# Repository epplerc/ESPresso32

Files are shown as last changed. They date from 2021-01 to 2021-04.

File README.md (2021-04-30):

# ESPresso32

The goal of this project is to create a espresso scale based on a ESP32 with
a corresponding Android App and Bluetooth Low Energy connection.

The ESP32 is programmed with the Arduino IDE.

A [demonstration video](https://youtu.be/5yW7n7iKzck) can be found on youtube.

## ESP32

### Software
You need the Arduino IDE to flash the software.
Simple flash the espresso32.ino file this is all.

Now you can install the Android app or use direct Bluetooth Low Energy
to communicate with the scale.

### Calibration
Your build scale will properly not sow correct values from the start.
To get correct values the scale need to be calibrated to do this
you need  a something where you know the weight.
At best it should not be to light.
Now start the scale but the calibration weight on it and start the [calibration modus](#characteristics).
If you want you can set a start calibration value for the auto calibration or determine a calibration
value by your own.
The calibration is done when the scale show the weight of you calibration weight.
You can monitor the status of the calibration with the [status characteristic](#characteristics).

This calibration value need to be set on every start of the scale. The android app to this on his own.

### Hardware setup
Beside of the software i have use a simple hardware setup which should only be a example without warranty.

#### List of components
Below you see a list of component i have used.
The advantage of the LiFePo4 accumulator are that they deliver a voltage from
max 3.6V which is the max voltage the ESP32 can be run direct on the 3.3V input.
So i was able to omitting one voltage converter.
As ESP32 i have used a plain wroom on a small circuit board.
If you want to do this too you need also a UART adapter to flash the ESP32.
You can also use a NodeMCU but this need more space and power.

- ESP32
- Load cell
- HX711
- Battery holder
- LiFePo4 accumulator
- Step up (MT3608)
- Housing ( **[My stl files are located here ](stl)**)
- (Optional) UART adapter
- Other small parts like wires etc

This is only a  simple example there for sure other setups possible.

**_NOTE:_** Depending on which HX711 module you have to should have a look here: [module design fault fix](https://github.com/bogde/HX711/issues/172)

#### Schematic

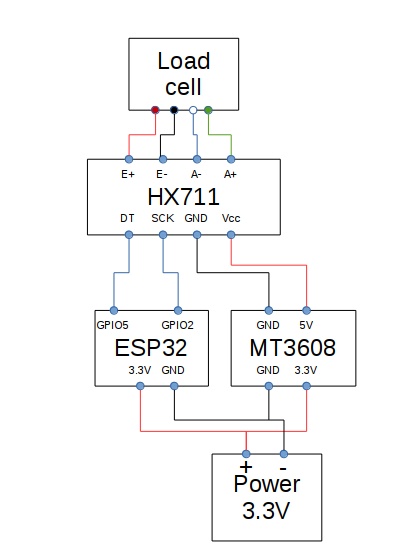
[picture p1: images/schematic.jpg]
Schematic


## Android
To use the android application you need a phone with **Bluetooth Low Energy**.

You can install the app from the [Playstore](https://play.google.com/store/apps/details?id=org.weblooker.espresso32) or build the app from the source.

If you want to build your application from the source you can do this.
The code is located in the folder  **[android](android)**.

## Bluetooth

### Service
The service UUID from the scale is **dff971a9-142a-4021-a8d2-f5298ab2bdbb**.

### Characteristics
Name | UUID | Read/Write  | Description | Value
------ | ------| ------| ------| ------
Settings   | 76053035-3aa1-4148-a70d-a73e35332418| x/x| Set the modus of the scale| tare, WEIGHT_MODUS, ESPRESSO_MODUS, CALIBRATION_MODUS
Status   | c5c78e8f-5963-4642-bd24-bbb8507e22ca|  x/-| Show the status of the scale|
Calibration weight   | 18d456b3-3c7b-43fa-9d3c-db867d2a93b2|  x/x| Calibration weight | Weight in g|
Calibration value   | e5c96eed-c523-4e81-9d8b-1f92f58603dc| x/x| Set a calibration value of get the determined one | 
Weight   | 2A98| x/-| Weight| Weight in g
Espresso weight   | d0dac8e6-cf56-4e0c-9823-0aed58dc9bfe|  x/-| The weight in g of espresso| 
Espresso time  | 6e980e27-b771-485a-8396-42f1dab56506|  x/-| Time| 

## Known Issues

### Espresso time is stop to early
Depending from your setup this can happen if you use a light espresso cup like a 
thermoglass in combination with vibrations from the pump. 
A simple fix is to use a heavy espresso cup. If this is not possible you need to play 
around with the threshold on the **messure_espresso()** function.
In future maybe this will configurable from the app.

## License

Copyright 2021 Christian Eppler

Licensed under the Apache License, Version 2.0 (the "License");
you may not use this file except in compliance with the License.
You may obtain a copy of the License at

    http://www.apache.org/licenses/LICENSE-2.0

Unless required by applicable law or agreed to in writing, software
distributed under the License is distributed on an "AS IS" BASIS,
WITHOUT WARRANTIES OR CONDITIONS OF ANY KIND, either express or implied.
See the License for the specific language governing permissions and
limitations under the License.

[Long License text](LICENSE)

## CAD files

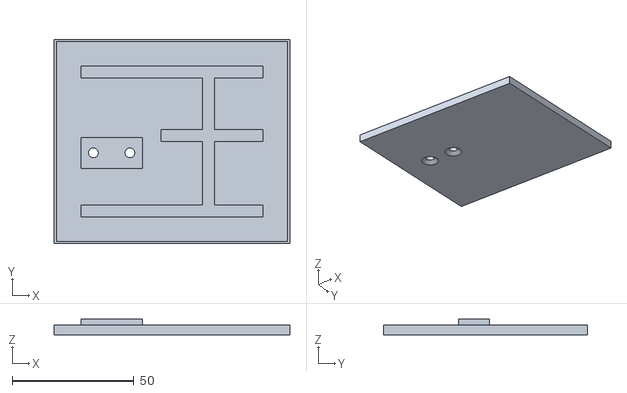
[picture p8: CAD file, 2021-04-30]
stl/top.stl
97.0 x 84.0 x 6.50

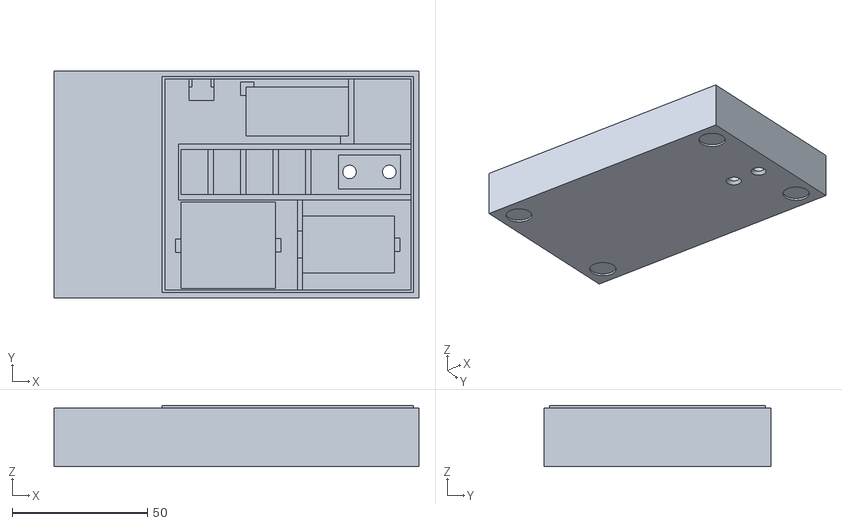
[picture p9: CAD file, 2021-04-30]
stl/housing.stl
135.0 x 84.0 x 22.7

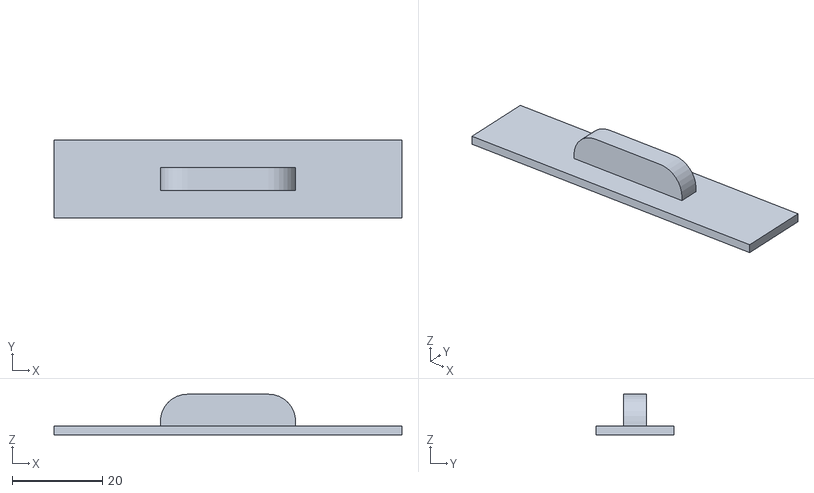
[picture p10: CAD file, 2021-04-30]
stl/lid.stl
77.2 x 17.2 x 9.00

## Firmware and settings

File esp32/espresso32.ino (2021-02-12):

#include "HX711.h"
#include <BLEDevice.h>
#include <BLEUtils.h>
#include <BLEServer.h>
#include <EEPROM.h>
#include <WiFi.h>

#define DEBUG false

#define LOADCELL_DOUT_PIN  5
#define LOADCELL_SCK_PIN  2
#define EEPROM_SIZE 5
#define EEPROM_VALUE_IS_STORED 142

#define WEIGHT_SERVICE_UUID "dff971a9-142a-4021-a8d2-f5298ab2bdbb"
#define SETTINGS_CHARACTERISTIC_UUID "76053035-3aa1-4148-a70d-a73e35332418"
#define STATUS_CHARACTERISTIC_UUID "c5c78e8f-5963-4642-bd24-bbb8507e22ca"
#define CALIBRATION_WEIGHT_CHARACTERISTIC_UUID "18d456b3-3c7b-43fa-9d3c-db867d2a93b2"
#define CALIBRATION_VALUE_CHARACTERISTIC_UUID "e5c96eed-c523-4e81-9d8b-1f92f58603dc"
#define WEIGHT_CHARACTERISTIC_UUID "2A98"
#define ESPRESSO_WEIGHT_CHARACTERISTIC_UUID "d0dac8e6-cf56-4e0c-9823-0aed58dc9bfe"
#define ESPRESSO_TIME_CHARACTERISTIC_UUID "6e980e27-b771-485a-8396-42f1dab56506"

HX711 scale;

union {
  float floatingpoint;
  char bytes[4];
} calibration_factor_union;
float default_calibration_factor = 4386.18; 

float tare_value = 0.0;
float weight = 0.0;
float tared_weight = 0.0;
float calibration_weight = 0.0;
boolean calibration_weight_is_set = false;

String modus = "WEIGHT_MODUS";
String state = "READY";

unsigned long espresso_start;
unsigned long espresso_end;
unsigned long espresso_time;

BLEServer *pServer;
BLEService *pService;
BLECharacteristic *pCharacteristicWeight;
BLECharacteristic *pCharacteristicCalibrationWeight;
BLECharacteristic *pCharacteristicCalibrationValue;
BLECharacteristic *pCharacteristicSettings;
BLECharacteristic *pCharacteristicStatus;
BLECharacteristic *pCharacteristicEspressoWeight;
BLECharacteristic *pCharacteristicEspressoTime;

float loadCalibrationValueFromFlash()
{
   if(EEPROM_VALUE_IS_STORED == EEPROM.read(4))
   {
      for(int i=0;i<4;i++)
      {
        calibration_factor_union.bytes[i] = EEPROM.read(i);
      }
      return calibration_factor_union.floatingpoint;
   }
   
   calibration_factor_union.floatingpoint = default_calibration_factor;
   return calibration_factor_union.floatingpoint;
}

void storeCalibrationValuetoFlash(float calvalue)
{
   calibration_factor_union.floatingpoint = calvalue;
  
   for(int i=0;i<4;i++)
    EEPROM.write(i,calibration_factor_union.bytes[i]);

   EEPROM.write(4,EEPROM_VALUE_IS_STORED);
   EEPROM.commit();
}

void setStatus(String state_param)
{
    state = state_param;
    pCharacteristicStatus->setValue(state.c_str());
    pCharacteristicStatus->notify();
}

void setModus(String modusParam)
{
  modus= modusParam;
  pCharacteristicSettings->setValue(modus.c_str());
  pCharacteristicSettings->notify();
}

void setCalibrationFaktor(float faktore)
{
   char result[50];
   sprintf(result,"%f",faktore);
   pCharacteristicCalibrationValue->setValue(result);
   pCharacteristicCalibrationValue->notify();
}

void setEspressoResult(long espresso_time,float tared_weight)
{
   String result = String();
   result.concat("{\"results\":[");
   char tmp_result[50];
   sprintf(tmp_result,"{\"t\":%d,\"w\":%.2f}",espresso_time,tared_weight);
   result.concat(String(tmp_result));
   result.concat("]}");
  
  char timeString[50];
  result.toCharArray(timeString,50); 
  pCharacteristicEspressoTime->setValue(timeString); 
  pCharacteristicEspressoTime->notify();
}

void setEspressoResults(unsigned long _times[], float weights[])
{
   char char_result[300];
   memset(char_result,'\0', 300);
   String result = String();
   result.concat("{\"results\":[");
   int delay_counter = 0;
   for(int i=0;i<10;i++)
   {
     if(weights[i] >= 0.0)
     {
       delay_counter++;
       char tmp_result[35];
       memset(tmp_result,'\0', sizeof(tmp_result));
       sprintf(tmp_result,"{\"t\":%d,\"w\":%.2f}",_times[i],weights[i]);
       result.concat(tmp_result);
  
       if(i >= 9)
        continue;

       if(weights[i+1] >= 0.0)
       {
         result.concat(',');
       }
       
     }
   }
   result.concat("]}");
   result.toCharArray(char_result,300); 

  pCharacteristicEspressoTime->setValue(char_result); 
  pCharacteristicEspressoTime->notify();
  delay(50*delay_counter); // Waiting until data is send
}

void setWeight(float weight_param)
{
  weight = weight_param;
  char floatString[20];
  sprintf(floatString,"%.2f",tared_weight);
  tared_weight = tareWeight(weight_param);
  pCharacteristicWeight->setValue(floatString);
  pCharacteristicWeight->notify();
#if DEBUG
  char output[50];
  sprintf(output,"Weight %.2f g",tared_weight);
  Serial.println(output);
#endif
}

class MyCallbacks: public BLECharacteristicCallbacks {
  
    void onWrite(BLECharacteristic *pCharacteristic) 
    {
      std::string value = pCharacteristic->getValue();
      if (value.length() > 0) 
      {
        String val = "";
        for (int i = 0; i < value.length(); i++){
          val  = val + value[i];
        }
#if DEBUG        
        Serial.println("Get value:"+val);
#endif        
        if(value == "tare")
        {
#if DEBUG           
           Serial.println("Tare weight");
#endif
           tare_value = weight;
        }
        if(value == "WEIGHT_MODUS")
        {
#if DEBUG
           Serial.println("Set modus to WEIGHT_MODUS");
#endif
           setModus("WEIGHT_MODUS");
        }
        if(value == "ESPRESSO_MODUS")
        {
#if DEBUG 
           Serial.println("Set modus to ESPRESSO_MODUS");
#endif
           setModus("ESPRESSO_MODUS");
        }
        if(value == "CALIBRATION_MODUS")
        {
#if DEBUG 
           Serial.println("Set modus to CALIBRATION_MODUS");
#endif
           setModus("CALIBRATION_MODUS");
        }
        
      }
    }
};

class CalibrationWeightCallbacks: public BLECharacteristicCallbacks {
  
    void onWrite(BLECharacteristic *pCharacteristic) 
    {
      std::string value = pCharacteristic->getValue();
      if (value.length() > 0) 
      {
        String val = "";
        for (int i = 0; i < value.length(); i++){
          val  = val + value[i];
        }
#if DEBUG 
        Serial.println("Get value:"+val);
#endif
        calibration_weight = val.toFloat();
        calibration_weight_is_set = true; 
      }
    }
};

class CalibrationValueCallbacks: public BLECharacteristicCallbacks {
  
    void onWrite(BLECharacteristic *pCharacteristic) 
    {      
      std::string value = pCharacteristic->getValue();
      if (value.length() > 0) 
      {
        String val = "";
        for (int i = 0; i < value.length(); i++){
          val  = val + value[i];
        }
#if DEBUG 
        Serial.println("Get value:"+val);
#endif

        storeCalibrationValuetoFlash(val.toFloat());
        scale.set_scale(calibration_factor_union.floatingpoint);
      }
    }
};

void setup() {
  Serial.begin(9600);

  WiFi.mode( WIFI_MODE_NULL );

  EEPROM.begin(EEPROM_SIZE);
  loadCalibrationValueFromFlash();

  int i = 0;
  while(!scale.is_ready())
  {
    scale.begin(LOADCELL_DOUT_PIN, LOADCELL_SCK_PIN);

    if(i > 0)
    {
      delay(100);
      Serial.println("Can't detect scale.");
    }
    i++;
  }
  scale.set_scale();
  scale.set_gain((byte)128);
  scale.tare();
  scale.set_scale(calibration_factor_union.floatingpoint);

  BLEDevice::init("ESPresso32");
  pServer = BLEDevice::createServer();
  pService = pServer->createService(WEIGHT_SERVICE_UUID);

  // BLECharacteristic::PROPERTY_WRITE
  pCharacteristicWeight = pService->createCharacteristic(
                                         WEIGHT_CHARACTERISTIC_UUID,
                                         BLECharacteristic::PROPERTY_READ|
                                         BLECharacteristic::PROPERTY_NOTIFY |
                                         BLECharacteristic::PROPERTY_INDICATE
                                       );

                                       
  pCharacteristicSettings = pService->createCharacteristic(
                                         SETTINGS_CHARACTERISTIC_UUID,
                                         BLECharacteristic::PROPERTY_READ |
                                         BLECharacteristic::PROPERTY_WRITE|
                                         BLECharacteristic::PROPERTY_NOTIFY |
                                         BLECharacteristic::PROPERTY_INDICATE
                                       );
  pCharacteristicEspressoWeight = pService->createCharacteristic(
                                         ESPRESSO_WEIGHT_CHARACTERISTIC_UUID,
                                         BLECharacteristic::PROPERTY_READ|
                                         BLECharacteristic::PROPERTY_NOTIFY |
                                         BLECharacteristic::PROPERTY_INDICATE
                                       );
  pCharacteristicEspressoTime = pService->createCharacteristic(
                                         ESPRESSO_TIME_CHARACTERISTIC_UUID,
                                         BLECharacteristic::PROPERTY_READ|
                                         BLECharacteristic::PROPERTY_NOTIFY |
                                         BLECharacteristic::PROPERTY_INDICATE
                                       );
  pCharacteristicStatus = pService->createCharacteristic(
                                         STATUS_CHARACTERISTIC_UUID,
                                         BLECharacteristic::PROPERTY_READ|
                                         BLECharacteristic::PROPERTY_NOTIFY |
                                         BLECharacteristic::PROPERTY_INDICATE
                                       );
  pCharacteristicCalibrationWeight = pService->createCharacteristic(
                                         CALIBRATION_WEIGHT_CHARACTERISTIC_UUID,
                                         BLECharacteristic::PROPERTY_READ |
                                         BLECharacteristic::PROPERTY_WRITE |
                                         BLECharacteristic::PROPERTY_NOTIFY |
                                         BLECharacteristic::PROPERTY_INDICATE
                                        );
  pCharacteristicCalibrationValue = pService->createCharacteristic(
                                         CALIBRATION_VALUE_CHARACTERISTIC_UUID,
                                         BLECharacteristic::PROPERTY_READ |
                                         BLECharacteristic::PROPERTY_WRITE|
                                         BLECharacteristic::PROPERTY_NOTIFY |
                                         BLECharacteristic::PROPERTY_INDICATE
                                         );

  pCharacteristicSettings->setCallbacks(new MyCallbacks());
  pCharacteristicCalibrationWeight->setCallbacks(new CalibrationWeightCallbacks());
  pCharacteristicCalibrationValue->setCallbacks(new CalibrationValueCallbacks());
 
  
  pService->start();
  BLEAdvertising *pAdvertising = BLEDevice::getAdvertising();
  pAdvertising->addServiceUUID(WEIGHT_SERVICE_UUID);
  pAdvertising->setScanResponse(true);
  pAdvertising->setMinPreferred(0x06);
  pAdvertising->setMinPreferred(0x12);
  BLEDevice::startAdvertising();

  setModus("WEIGHT_MODUS");
  setCalibrationFaktor(calibration_factor_union.floatingpoint);
  setStatus("READY");
}

void tare()
{
  tare_value += tared_weight;
}

void messure_weight()
{
#if DEBUG
  Serial.print("Reading: ");
#endif
  setWeight(scale.get_units(5));
}

void messure_weight_calibrate()
{
#if DEBUG
  Serial.print("Reading: ");
#endif
  setWeight(scale.get_units(10));
}

void messure_weight_fast()
{
#if DEBUG 
  Serial.print("Reading fast: ");
#endif
  setWeight(scale.get_units(1));
}

float tareWeight(float weight_param)
{
  return weight_param - tare_value;
}

//TODO  make a reset that we not get into infinite loop
// have in minde negative values (do a error flag and make a reboot posible from bluethooth?)
void messure_espresso()
{

  setStatus("TARE");
  do{
#if DEBUG
    Serial.println("Tare...");
#endif
    tare();
    delay(100);
    messure_weight();
  }while(tared_weight > 0.1);
#if DEBUG     
  Serial.print("Waiting for coffee..");
#endif
  setStatus("WAITING");
  
  float start_weight = scale.get_units(3);
  int sameCounter = 0;
  int tmp_index = 0;
  float tmp_weights[10] = {-1,-1,-1,-1,-1,-1,-1,-1,-1,-1};
  unsigned long tmp_times[10] = {-1,-1,-1,-1,-1,-1,-1,-1,-1,-1};
  while(true)
  {
    float tmp_weight = scale.get_units(3);
    if(tmp_weight-start_weight > 0.2)
    {      
      
      if(sameCounter == 0)
      {
       espresso_start = millis();
      }

      setWeight(tmp_weight);
      tmp_weights[tmp_index] = tared_weight;
      tmp_times[tmp_index] = millis()-espresso_start;
      tmp_index++;
      sameCounter++;
    }
    else
    {
      for(int i=0;i<10;i++)
      {
        tmp_weights[i] = -1;
        tmp_times[i] = -1;
      }
      tmp_index = 0; 
      sameCounter=0;
    }

    
    if(start_weight-tmp_weight > 0.2 )
    {
#if DEBUG
      Serial.print("Seem to me that the weight of the cup has changed will tare this. ;-)");
#endif
      setWeight(scale.get_units(3));
      tare();
      start_weight = scale.get_units(3);
    }

    if(sameCounter >= 7)
    {
      break;  
    }
#if DEBUG   
    Serial.println("Waiting...");
#endif
  }
  setStatus("MEASSURE");
  
  // Sent stored tmp results to get complete diagram
  setEspressoResults(tmp_times,tmp_weights);


  for(int i=0;i<10;i++)
  {
    tmp_weights[i] = -1;
    tmp_times[i] = -1;
  }
  tmp_index = 0; 
  sameCounter = 0;
  unsigned long espresso_end_tmp;
  float weight_before = 0.0;
  while(true)
  {
#if DEBUG 
    Serial.println("Coffee flows....");
#endif    
    float tmp_weight = scale.get_units(3);
    unsigned long time_on_weight = millis();
    float weight_diff = fabs(tmp_weight-weight_before);
    setWeight(tmp_weight);

    if(weight_diff < 0.2 )
    {
      if(sameCounter == 0)
      {
        espresso_end_tmp = time_on_weight;
      }
      tmp_weights[tmp_index] = tared_weight;
      tmp_times[tmp_index] = time_on_weight-espresso_start;
      tmp_index++;
      sameCounter++;
    }
    else if(sameCounter > 0) // It seem that there was a change again its not the end until now
    {
      weight_before=weight;
      setEspressoResults(tmp_times,tmp_weights);
      for(int i=0;i<10;i++)
      {
        tmp_weights[i] = -1;
        tmp_times[i] = -1;
      }
      tmp_index = 0; 
      sameCounter = 0;
      continue;
    }
    
    if(sameCounter >= 3)
    {
      espresso_end = espresso_end_tmp;
      break;
    }

    if(sameCounter == 0) // Without this check the diagram can have a back jump
    {
      setEspressoResult(time_on_weight-espresso_start,tared_weight);
      weight_before=weight;
    }
  }
  espresso_time = espresso_end - espresso_start;
#if DEBUG 
  Serial.print("Espresso is ready :-)");
#endif  
  setEspressoResult(espresso_time,tared_weight);
  setModus("WEIGHT_MODUS");
  setStatus("READY");
}

void calibrate()
{
  float allowed_delta = 20.00; // unit g
  float add_factor = 50.00;

#if DEBUG  
  Serial.print("Waiting for calibration weight");
#endif  
  pCharacteristicStatus->setValue("WAITING_FOR_CALIBRATION_WEIGHT");
  while(!calibration_weight_is_set)
  {
   Serial.println("Waiting..."); 
   delay(10);
  }
  char status_message[20];
#if DEBUG 
  char message[100];
  sprintf(message,"Callibration weight is set to %.2f. Start Auto calibration. Please wait...",calibration_weight);
#endif
  setStatus("AUTO_CALIBRATE");
 
  messure_weight_fast();
  int phase = 1;
  
  int switching = 1;
  float weight_before = weight;
  int switchBack= 0;
  while(true)
  {
#if DEBUG 
    char message[100];
    sprintf(message,"Calibrate phase %d ... factor is now %.3f.",phase,calibration_factor_union.floatingpoint);
    Serial.println(message);
#endif
    if(fabs(weight-calibration_weight) <= allowed_delta)
    {
      phase++;
      allowed_delta = allowed_delta / 10;
      add_factor = add_factor / 10;
      
      if(phase > 5)
      {
        break;
      }
      
      sprintf(status_message,"AUTO_CALIBRATE_PHASE_%d",phase);
      setStatus(status_message);
      switchBack= 0;
    }
    else{
      switchBack++;
    }

    if(switchBack > 1000) // We seem to stuck try another starting point
    {
      allowed_delta = 20.00;
      add_factor = 50.00;
      switchBack = 0;
      phase = 1;
      calibration_factor_union.floatingpoint = random(-10000.0,+10000.0);
      continue;
    }

    if(fabs(weight-calibration_weight) > fabs(weight_before-calibration_weight))
    {
      switching = (switching+1)%2;
    }

    if(switching == 1)
    {
      calibration_factor_union.floatingpoint += add_factor;
      scale.set_scale(calibration_factor_union.floatingpoint);
    }
    else if (switching == 0)
    {
      calibration_factor_union.floatingpoint -= add_factor;
      scale.set_scale(calibration_factor_union.floatingpoint);
    }

    weight_before = weight;
    if(phase < 4)
    {
      messure_weight_fast();
    }
    else
    {
      messure_weight_calibrate();
    }
    delay(10);
  }

  delay(100);
  setCalibrationFaktor(calibration_factor_union.floatingpoint);
  calibration_weight_is_set = false;
  setModus("WEIGHT_MODUS");
  setStatus("READY");
}

void loop() {

  if(modus == "WEIGHT_MODUS")
  {
    messure_weight();
  }
  if(modus == "ESPRESSO_MODUS")
  {
    messure_espresso();
  }
  if(modus == "CALIBRATION_MODUS")
  {
    calibrate();
  }
}

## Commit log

2021-01-16 Initial commit with esp32 file and folder structure.
2021-01-17 Add schematic image to readme
2021-01-19 Extend readme with text about calibration
2021-01-22 Fix schematic image.
2021-01-28 Store calibration value on flash. Extend calibration function.
2021-02-13 Change to material design.
2021-04-30 Add stl files.
    [housing.stl, lid.stl, top.stl]
